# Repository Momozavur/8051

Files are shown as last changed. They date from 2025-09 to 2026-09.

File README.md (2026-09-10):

# 8051

KiCad design files for 8051.

## Project files

- [8051 Breakout Board/8051_breakout.kicad_pro](8051%20Breakout%20Board/8051_breakout.kicad_pro)
- [8051 Development Board v2/8051.kicad_pro](8051%20Development%20Board%20v2/8051.kicad_pro)
- [8051 Development Board/8051.kicad_pro](8051%20Development%20Board/8051.kicad_pro)
- [8051 ultra/Ultra_DB_X51_v1.kicad_pro](8051%20ultra/Ultra_DB_X51_v1.kicad_pro)
- [8051 ultra/Ultra_DB_X51_v1.pro](8051%20ultra/Ultra_DB_X51_v1.pro)
- [8051 ultra/file549BD866.kicad_pro](8051%20ultra/file549BD866.kicad_pro)
- [8051 ultra/file549BD866.pro](8051%20ultra/file549BD866.pro)
- [8051 ultra/file549BDEFB.pro](8051%20ultra/file549BDEFB.pro)
- [8051 ultra/file549BE66B.pro](8051%20ultra/file549BE66B.pro)

Open the appropriate `.kicad_pro` file in KiCad; `.pro` entries are legacy projects. Keep schematics, boards, local libraries, library tables, and supporting files together. Hierarchical schematic sheets are part of their parent design.

## Git workflow

Automatic backups, recovery files, editor state, and filesystem metadata are ignored. Existing fabrication outputs and local component libraries are retained. For existing repositories, ignore rules do not automatically untrack previously committed files.

Review and save a meaningful design revision with:

```sh
git status --short
git diff
git add -- <changed-files>
git commit -m "Describe the design change"
```

## Documentation images

Add a clear 3D board view at `docs/images/board-3d.png` and, optionally, a PCB layout view at `docs/images/pcb-layout.png`. A schematic PDF is useful for reading circuit details. Once present, embed an image in this README with `![Board 3D view](docs/images/board-3d.png)`. For folders with several designs, use a separate named image for each.

## Design notes to complete

Describe purpose, power and connectors, revision status, assembly requirements, and what has been physically tested. The repository setup does not establish electrical correctness or manufacturing readiness.

## Repository portability notes

- Computer-specific library path: `8051 ultra/fp-lib-table` → `H:\\PCB_Designes\\LPC1768 Stick1\\lib_new\\logo.pretty`.
- Computer-specific library path: `8051 ultra/fp-lib-table` → `H:\\PCB_Designes\\LPC1768 Stick1\\lib_new\\New_Logo.pretty`.

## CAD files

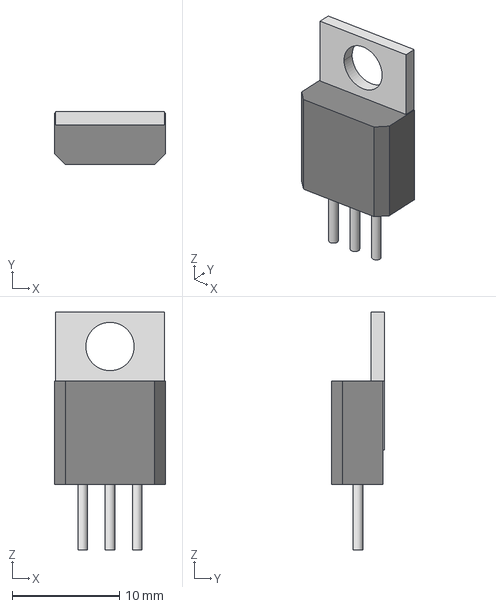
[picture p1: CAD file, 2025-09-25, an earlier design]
8051 Development Board v2/imports/2SA2222SG/TO-220F-3SG_15P87X10P16_ONS.step
10.4 x 4.90 x 22.2 mm

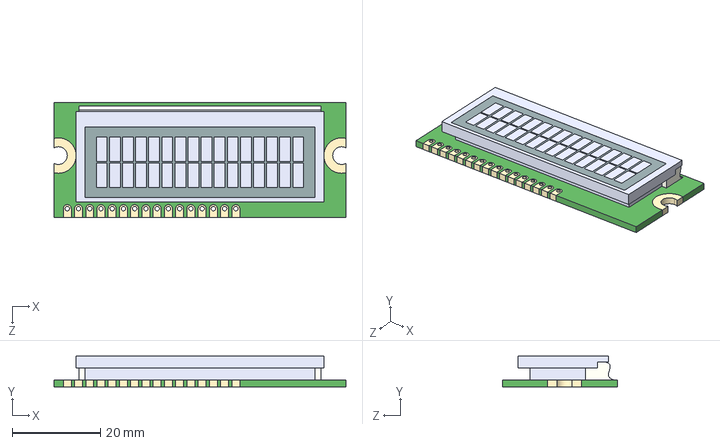
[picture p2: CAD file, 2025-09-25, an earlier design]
8051 Development Board v2/imports/LCM_S01602DTR_M/LCM-S01602DTR_M.STEP
66.0 x 7.00 x 26.0 mm

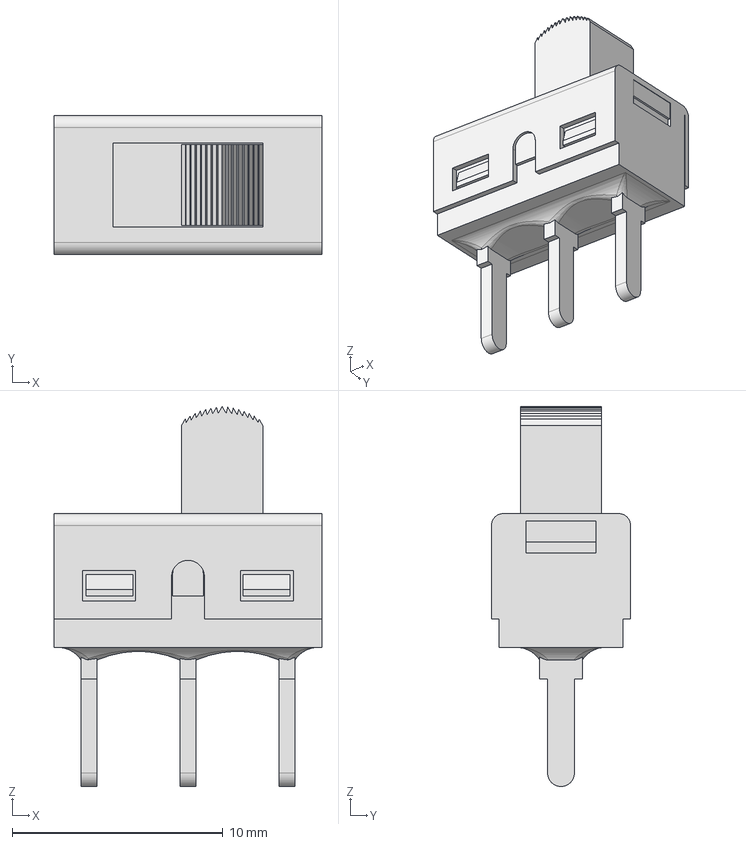
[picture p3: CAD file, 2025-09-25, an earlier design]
8051 Development Board v2/imports/LIB_500SSP1S1M2QEA/500SSP1S1M2QEA/3D/500SSP1S1M2QEA.stp
12.7 x 6.60 x 18.0 mm

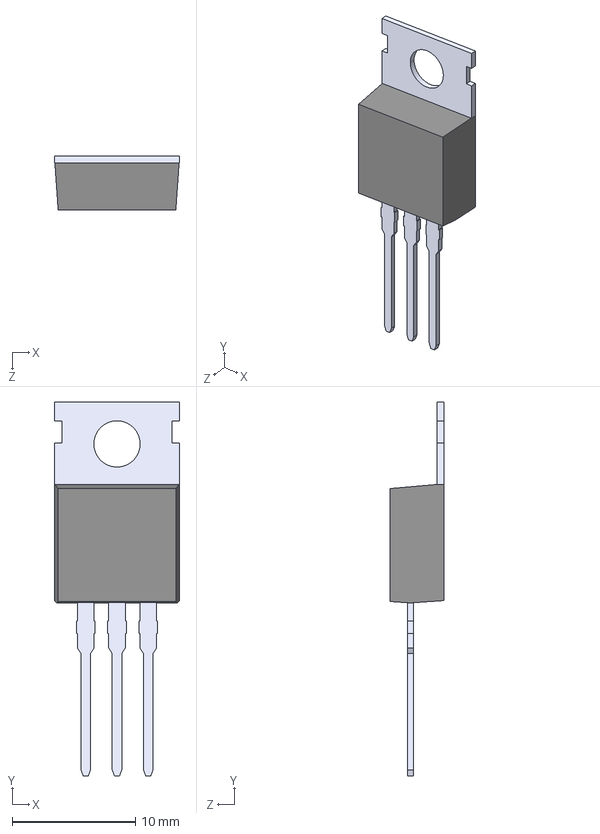
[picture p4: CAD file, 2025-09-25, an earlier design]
8051 Development Board v2/imports/LM7805CT/LM7805CT_NOPB.step
10.2 x 30.3 x 4.35 mm

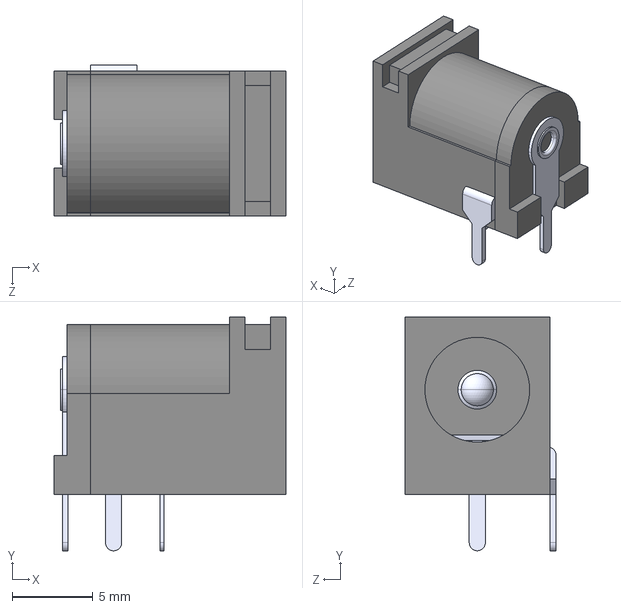
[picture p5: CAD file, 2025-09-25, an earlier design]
8051 Development Board v2/imports/PJ_102A-2/PJ-102A.step
14.4 x 14.5 x 9.40 mm

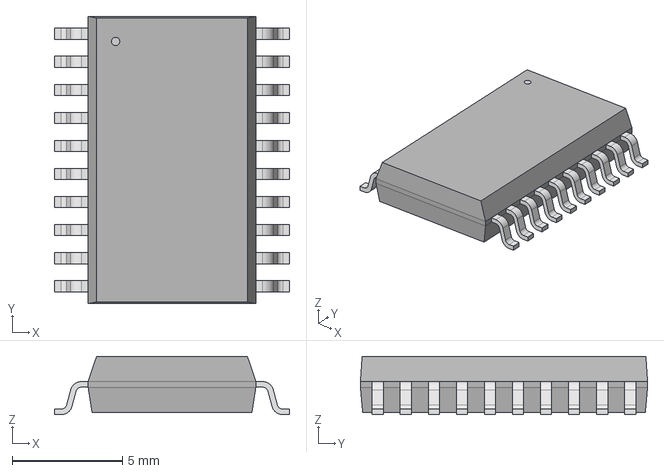
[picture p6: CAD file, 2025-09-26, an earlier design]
8051 Development Board v2/imports/SOIC20_12P7X5P4_ONS.step
10.6 x 13.0 x 2.64 mm

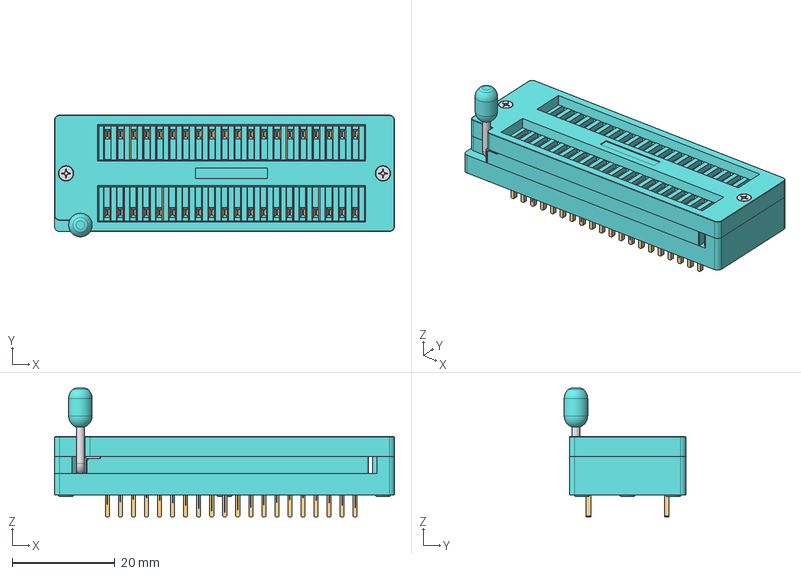
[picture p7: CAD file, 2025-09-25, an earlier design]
8051 Development Board v2/imports/ZIF_40_uni.stp
66.2 x 23.7 x 25.1 mm
ZIF_40uni_bottom
ZIF_40uni_middle_body
ZIF_wide_middle_shield
ZIF_40uni_top
ZIF_handle_wide
ZIF_socket_handle_head
ZIF_socket_pin_uni x 40
M1.6-L8 x 2

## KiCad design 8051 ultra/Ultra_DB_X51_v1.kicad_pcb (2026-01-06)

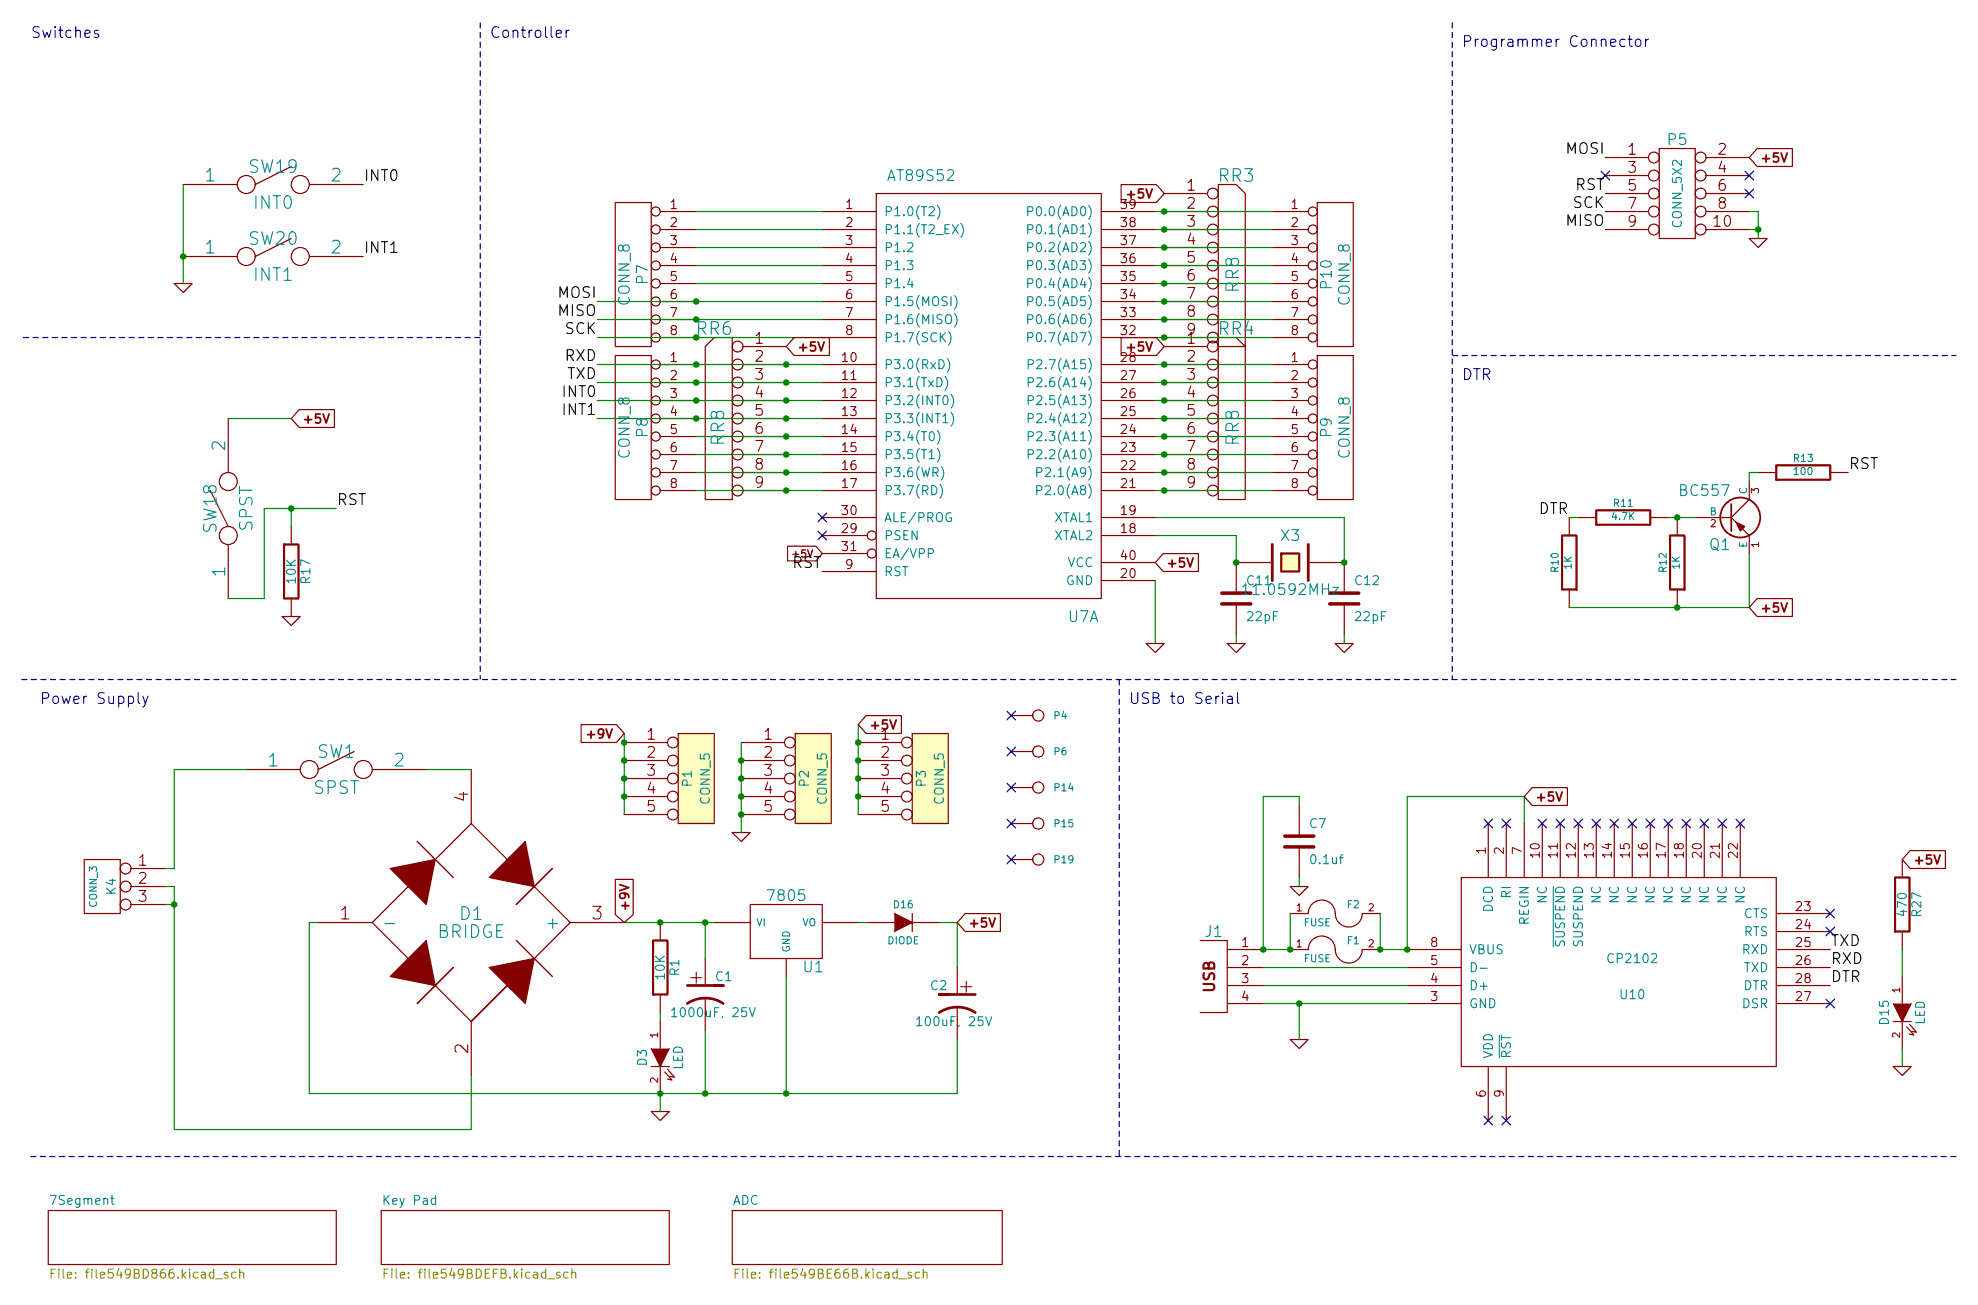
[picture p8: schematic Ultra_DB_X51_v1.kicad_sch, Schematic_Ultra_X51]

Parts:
C1: 1000uF, 25V
C2: 100uF, 25V
C7: 0.1uf
C11, C12: 22pF
D1: BRIDGE
D3, D15: LED
D16: DIODE
F1, F2: FUSE
J1: USB_2
K4: CONN_3
P1, P2, P3: CONN_5
P4, P6, P14, P15, P19: CONN_1
P5: CONN_5X2
P7, P8, P9, P10: CONN_8
Q1: BC557
R1, R17: 10K
R10, R12: 1K
R11: 4.7K
R13: 100
R27: 470
RR3, RR4, RR6: RR8
SW1, SW18: SPST
SW19: INT0
SW20: INT1
U1: 7805
U7: AT89S52
U10: CP2102; MODULE
X3: 11.0592MHz

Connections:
+5V: C2.1, D16.2 (K), F1.2, F2.2, P3.1, P3.2, P3.3, P3.4, P3.5, P5.2, Q1.1 (E), R10.1, R12.1, R27.2, RR3.1 (COM), RR4.1 (COM), RR6.1 (COM), SW18.2, U7.31 (EA/VPP), U7.40 (VCC), U10.7 (REGIN), U10.8 (VBUS); also elsewhere on the board
+9V: C1.1, D1.3 (+), P1.1, P1.2, P1.3, P1.4, P1.5, R1.2, U1.VI; also elsewhere on the board
/DTR: R10.2, R11.1, U10.28 (DTR)
/INT0: P8.3, RR6.4, SW19.2, U7.12 (P3.2(INT0))
/INT1: P8.4, RR6.5, SW20.2, U7.13 (P3.3(INT1))
/MISO: P5.9, P7.7, U7.7 (P1.6(MISO))
/MOSI: P5.1, P7.6, U7.6 (P1.5(MOSI))
/RST: P5.5, R13.2, R17.1, SW18.1, U7.9 (RST)
/RXD: P8.1, RR6.2, U7.10 (P3.0(RxD)), U10.26 (TXD)
/SCK: P5.7, P7.8, U7.8 (P1.7(SCK))
/TXD: P8.2, RR6.3, U7.11 (P3.1(TxD)), U10.25 (RXD)
GND: C1.2, C2.2, C7.2, C11.2, C12.2, D1.1 (-), D3.2 (K), D15.2 (K), J1.4, P2.1, P2.2, P2.3, P2.4, P2.5, P5.8, P5.10, R17.2, SW19.1, SW20.1, U1.GND, U7.20 (GND), U10.3 (GND); also elsewhere on the board
unnamed: J1.2, U10.5 (D-)
unnamed: Q1.2 (B), R11.2, R12.2
unnamed: J1.3, U10.4 (D+)
unnamed: Q1.3 (C), R13.1
unnamed: C7.1, F1.1, F2.1, J1.1
unnamed: D1.2, K4.2 (PM), K4.3
unnamed: P7.5, U7.5 (P1.4)
unnamed: P7.4, U7.4 (P1.3)
unnamed: P7.3, U7.3 (P1.2)
unnamed: P7.2, U7.2 (P1.1(T2_EX))
unnamed: P7.1, U7.1 (P1.0(T2))
unnamed: D16.1 (A), U1.VO
unnamed: C12.1, U7.19 (XTAL1), X3.2
unnamed: C11.1, U7.18 (XTAL2), X3.1
unnamed: D3.1 (A), R1.1
unnamed: D15.1 (A), R27.1
unnamed: K4.1, SW1.1
unnamed: D1.4, SW1.2
unnamed: P8.5, RR6.6, U7.14 (P3.4(T0))
unnamed: P8.8, RR6.9, U7.17 (P3.7(RD))
unnamed: P8.7, RR6.8, U7.16 (P3.6(WR))
unnamed: P8.6, RR6.7, U7.15 (P3.5(T1))
unnamed: P9.8, RR4.9, U7.21 (P2.0(A8))
unnamed: P9.7, RR4.8, U7.22 (P2.1(A9))
unnamed: P9.6, RR4.7, U7.23 (P2.2(A10))
unnamed: P9.5, RR4.6, U7.24 (P2.3(A11))
unnamed: P9.4, RR4.5, U7.25 (P2.4(A12))
unnamed: P9.3, RR4.4, U7.26 (P2.5(A13))
unnamed: P9.2, RR4.3, U7.27 (P2.6(A14))
unnamed: P9.1, RR4.2, U7.28 (P2.7(A15))
unnamed: P10.2, RR3.3, U7.38 (P0.1(AD1))
unnamed: P10.8, RR3.9, U7.32 (P0.7(AD7))
unnamed: P10.7, RR3.8, U7.33 (P0.6(AD6))
unnamed: P10.6, RR3.7, U7.34 (P0.5(AD5))
unnamed: P10.5, RR3.6, U7.35 (P0.4(AD4))
unnamed: P10.4, RR3.5, U7.36 (P0.3(AD3))
unnamed: P10.3, RR3.4, U7.37 (P0.2(AD2))
unnamed: P10.1, RR3.2, U7.39 (P0.0(AD0))

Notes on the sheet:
DTR
Switches
Power Supply
Programmer Connector
Controller
USB to Serial

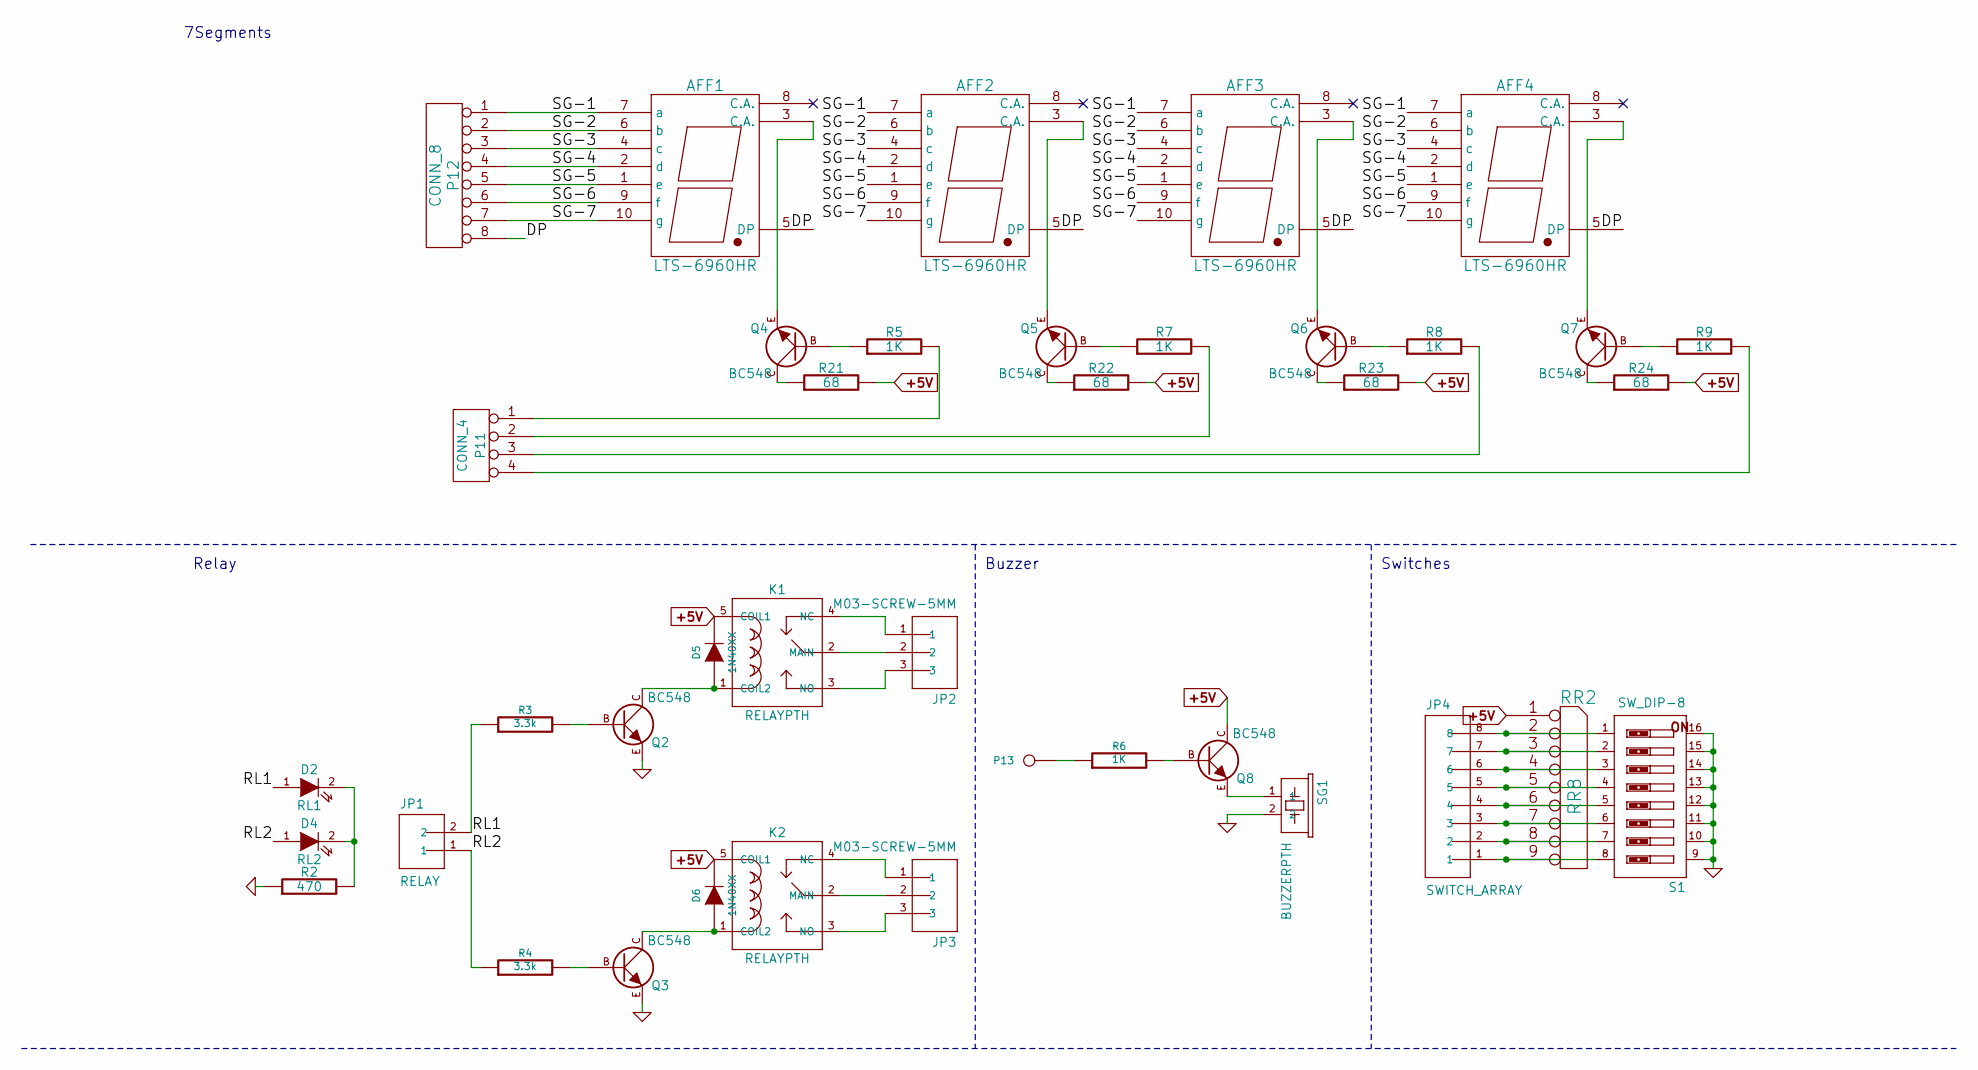
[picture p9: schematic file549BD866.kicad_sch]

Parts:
AFF1, AFF2, AFF3, AFF4: LTS-6960HR
D2: RL1
D4: RL2
D5, D6: 1N40XX
JP1: RELAY; SparkFun-JST-2-PTH-NS
JP2, JP3: M03-SCREW-5MM; SparkFun-SCREWTERMINAL-5MM-3
JP4: SWITCH_ARRAY; SparkFun-1X08_LOCK
K1, K2: RELAYPTH
P11: CONN_4
P12: CONN_8
P13: CONN_1
Q2, Q3, Q4, Q5, Q6, Q7, Q8: BC548; TO92-EBC
R2: 470
R3, R4: 3.3k
R5, R7, R8, R9: 1K
R6: 1K
R21, R22, R23, R24: 68
RR2: RR8
S1: SW_DIP-8; SparkFun-DIPSWITCH-08
SG1: BUZZERPTH; SparkFun-BUZZER-12MM

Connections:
+5V: D5.2 (K), D6.2 (K), K1.5 (COIL1), K2.5 (COIL1), Q8.C, R21.2, R22.2, R23.2, R24.2, RR2.1 (COM); also elsewhere on the board
/7Segment/DP: AFF1.5 (DP), AFF2.5 (DP), AFF3.5 (DP), AFF4.5 (DP), P12.8
/7Segment/RL1: D2.1 (A), JP1.2, R3.1
/7Segment/RL2: D4.1 (A), JP1.1, R4.1
/7Segment/SG-1: AFF1.7 (a), AFF2.7 (a), AFF3.7 (a), AFF4.7 (a), P12.1
/7Segment/SG-2: AFF1.6 (b), AFF2.6 (b), AFF3.6 (b), AFF4.6 (b), P12.2
/7Segment/SG-3: AFF1.4 (c), AFF2.4 (c), AFF3.4 (c), AFF4.4 (c), P12.3
/7Segment/SG-4: AFF1.2 (d), AFF2.2 (d), AFF3.2 (d), AFF4.2 (d), P12.4
/7Segment/SG-5: AFF1.1 (e), AFF2.1 (e), AFF3.1 (e), AFF4.1 (e), P12.5
/7Segment/SG-6: AFF1.9 (f), AFF2.9 (f), AFF3.9 (f), AFF4.9 (f), P12.6
/7Segment/SG-7: AFF1.10 (g), AFF2.10 (g), AFF3.10 (g), AFF4.10 (g), P12.7
GND: Q2.E, Q3.E, R2.1, S1.9, S1.10, S1.11, S1.12, S1.13, S1.14, S1.15, S1.16, SG1.2; also elsewhere on the board
unnamed: Q2.B, R3.2
unnamed: Q3.B, R4.2
unnamed: D6.1 (A), K2.1 (COIL2), Q3.C
unnamed: P11.1, R5.2
unnamed: D5.1 (A), K1.1 (COIL2), Q2.C
unnamed: P11.4, R9.2
unnamed: P11.3, R8.2
unnamed: P11.2, R7.2
unnamed: Q8.E, SG1.1
unnamed: Q8.B, R6.2
unnamed: P13.1, R6.1
unnamed: AFF4.3 (C.A.), Q7.E
unnamed: Q7.C, R24.1
unnamed: Q6.C, R23.1
unnamed: Q5.C, R22.1
unnamed: Q4.C, R21.1
unnamed: AFF2.3 (C.A.), Q5.E
unnamed: JP2.3, K1.3 (NO)
unnamed: JP2.2, K1.2 (MAIN)
unnamed: JP2.1, K1.4 (NC)
unnamed: JP4.8, RR2.2, S1.1
unnamed: JP3.1, K2.4 (NC)
unnamed: JP3.2, K2.2 (MAIN)
unnamed: D2.2 (K), D4.2 (K), R2.2
unnamed: JP4.1, RR2.9, S1.8
unnamed: JP4.2, RR2.8, S1.7
unnamed: JP4.3, RR2.7, S1.6
unnamed: JP4.4, RR2.6, S1.5
unnamed: JP4.5, RR2.5, S1.4
unnamed: JP4.6, RR2.4, S1.3
unnamed: JP4.7, RR2.3, S1.2
unnamed: JP3.3, K2.3 (NO)
unnamed: Q6.B, R8.1
unnamed: Q7.B, R9.1
unnamed: Q4.B, R5.1
unnamed: Q5.B, R7.1
unnamed: AFF1.3 (C.A.), Q4.E
unnamed: AFF3.3 (C.A.), Q6.E

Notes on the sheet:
7Segments
Buzzer
Switches
Relay

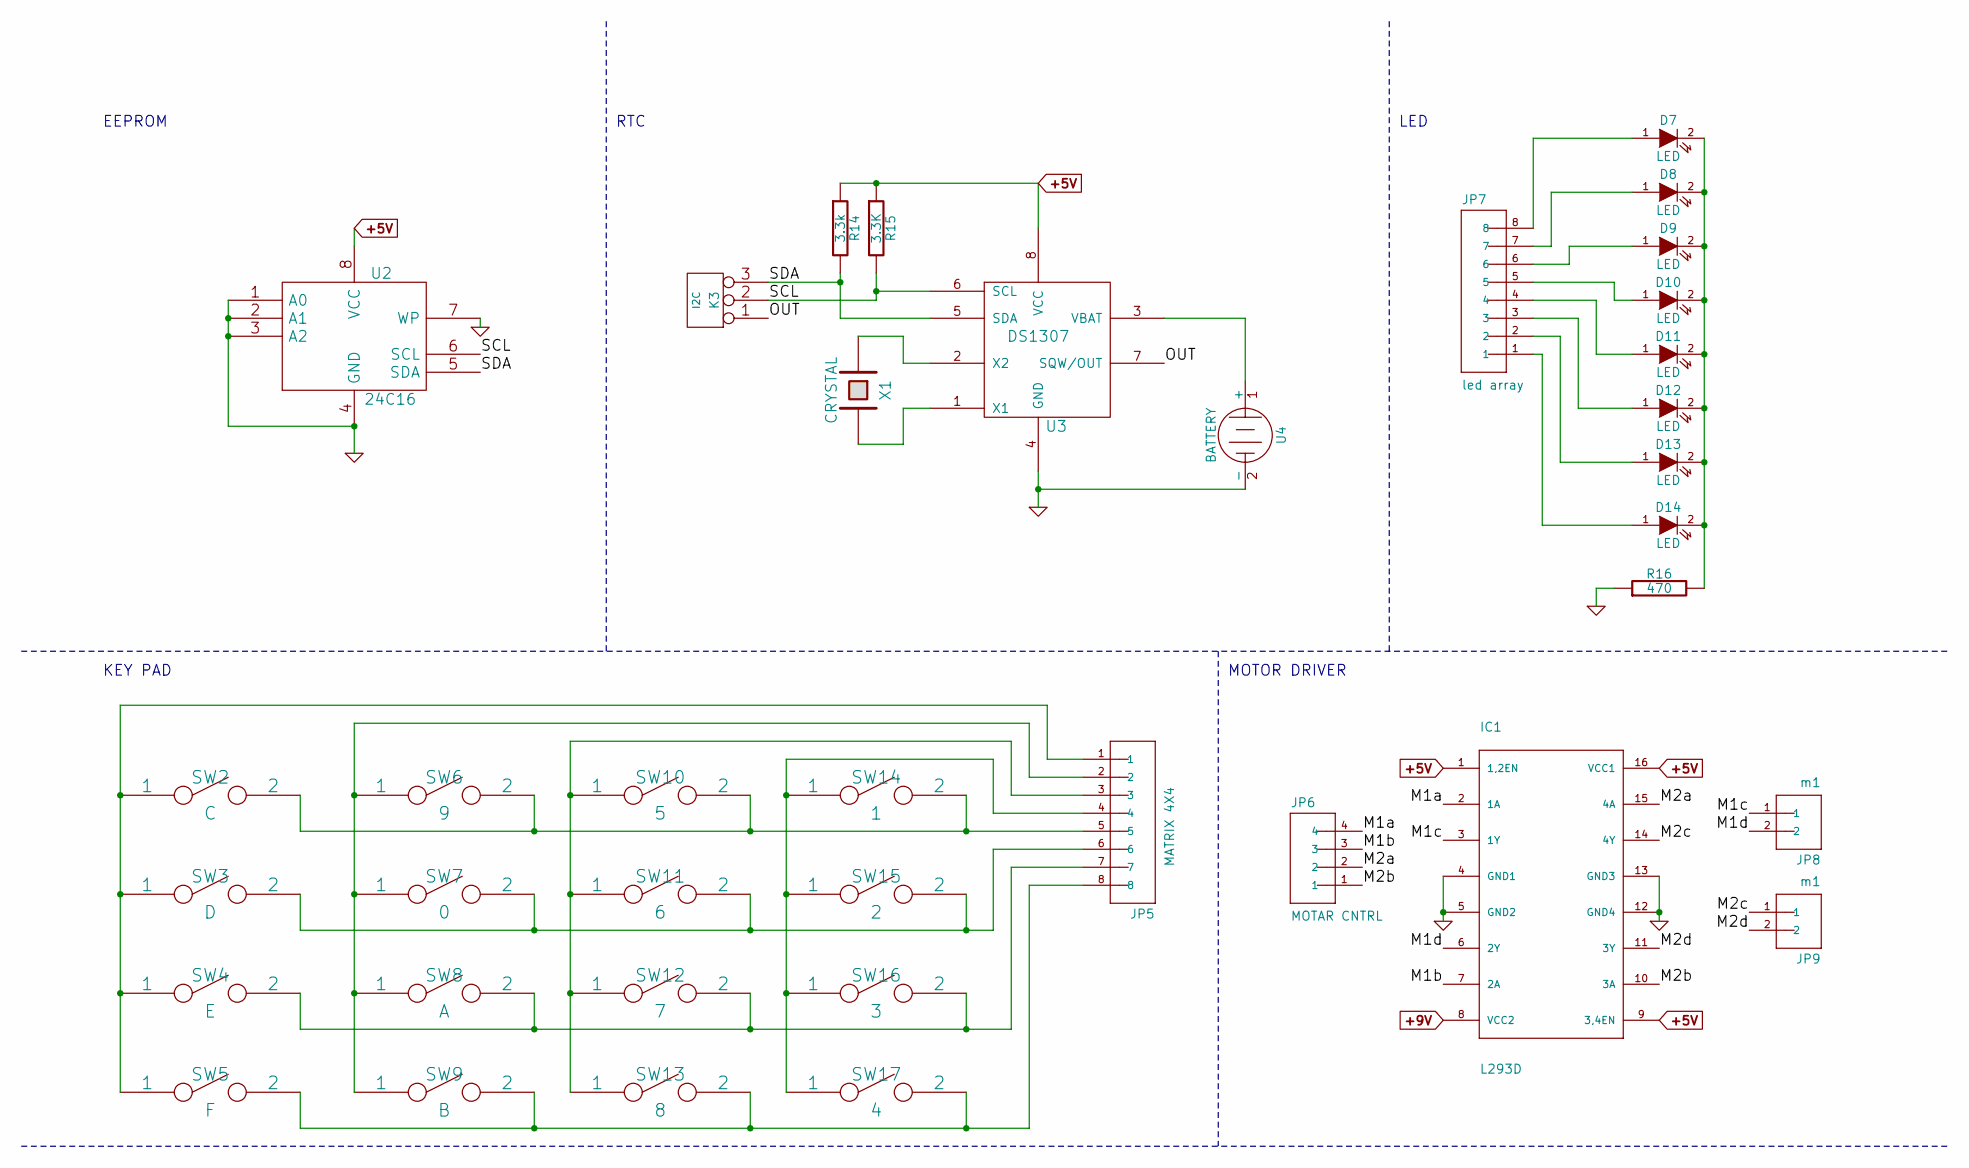
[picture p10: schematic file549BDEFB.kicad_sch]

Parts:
D7, D8, D9, D10, D11, D12, D13, D14: LED
IC1: L293D; sgs-thom-DIL16
JP5: MATRIX 4X4; SparkFun-1X08_LOCK
JP6: MOTAR CNTRL; SparkFun-JST-4-PTH
JP7: led array; SparkFun-1X08_LOCK
JP8, JP9: m1; SparkFun-JST-2-PTH-NS
K3: I2C
R14: 3.3k
R15: 3.3K
R16: 470
SW2: C
SW3: D
SW4: E
SW5: F
SW6: 9
SW7: 0
SW8: A
SW9: B
SW10: 5
SW11: 6
SW12: 7
SW13: 8
SW14: 1
SW15: 2
SW16: 3
SW17: 4
U2: 24C16
U3: DS1307
U4: BATTERY
X1: CRYSTAL

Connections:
+5V: IC1.1 (1,2EN), IC1.9 (3,4EN), IC1.16 (VCC1), R14.1, R15.1, U2.8 (VCC), U3.8 (VCC); also elsewhere on the board
+9V: IC1.8 (VCC2); also elsewhere on the board
/Key Pad/M1a: IC1.2 (1A), JP6.4
/Key Pad/M1b: IC1.7 (2A), JP6.3
/Key Pad/M1c: IC1.3 (1Y), JP8.1
/Key Pad/M1d: IC1.6 (2Y), JP8.2
/Key Pad/M2a: IC1.15 (4A), JP6.2
/Key Pad/M2b: IC1.10 (3A), JP6.1
/Key Pad/M2c: IC1.14 (4Y), JP9.1
/Key Pad/M2d: IC1.11 (3Y), JP9.2
/Key Pad/OUT: K3.1, U3.7 (SQW/OUT)
/Key Pad/SCL: K3.2 (PM), R15.2, U2.6 (SCL), U3.6 (SCL)
/Key Pad/SDA: K3.3, R14.2, U2.5 (SDA), U3.5 (SDA)
GND: IC1.4 (GND1), IC1.5 (GND2), IC1.12 (GND4), IC1.13 (GND3), R16.1, U2.1 (A0), U2.2 (A1), U2.3 (A2), U2.4 (GND), U2.7 (WP), U3.4 (GND), U4.2 (-); also elsewhere on the board
unnamed: D8.1 (A), JP7.7
unnamed: D9.1 (A), JP7.6
unnamed: D10.1 (A), JP7.5
unnamed: D11.1 (A), JP7.4
unnamed: D12.1 (A), JP7.3
unnamed: D13.1 (A), JP7.2
unnamed: D7.1 (A), JP7.8
unnamed: U3.2 (X2), X1.1
unnamed: U3.1 (X1), X1.2
unnamed: U3.3 (VBAT), U4.1 (+)
unnamed: D14.1 (A), JP7.1
unnamed: JP5.7, SW4.2, SW8.2, SW12.2, SW16.2
unnamed: JP5.8, SW5.2, SW9.2, SW13.2, SW17.2
unnamed: JP5.5, SW2.2, SW6.2, SW10.2, SW14.2
unnamed: JP5.6, SW3.2, SW7.2, SW11.2, SW15.2
unnamed: JP5.3, SW10.1, SW11.1, SW12.1, SW13.1
unnamed: JP5.2, SW6.1, SW7.1, SW8.1, SW9.1
unnamed: JP5.4, SW14.1, SW15.1, SW16.1, SW17.1
unnamed: JP5.1, SW2.1, SW3.1, SW4.1, SW5.1
unnamed: D7.2 (K), D8.2 (K), D9.2 (K), D10.2 (K), D11.2 (K), D12.2 (K), D13.2 (K), D14.2 (K), R16.2

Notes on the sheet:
EEPROM
KEY PAD
LED
RTC
MOTOR DRIVER

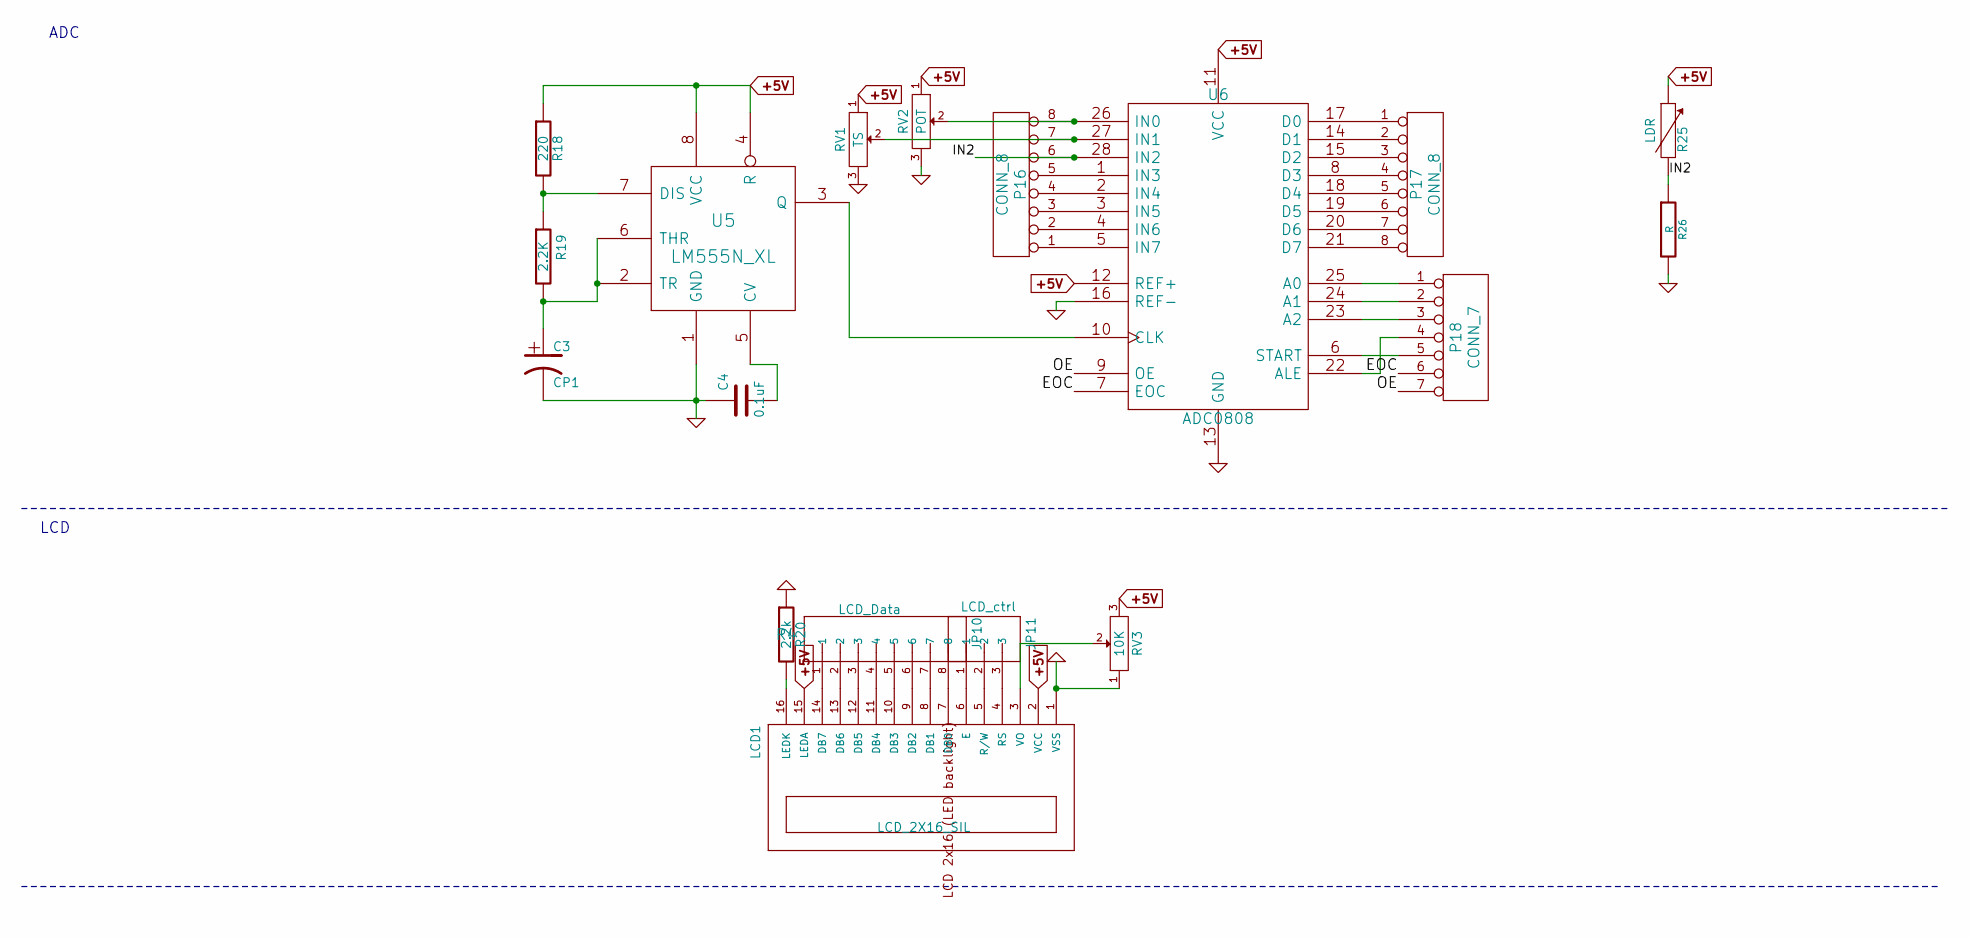
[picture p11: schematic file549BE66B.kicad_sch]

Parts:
C3: CP1
C4: 0.1uF
JP10: LCD_Data; SparkFun-1X08
JP11: LCD_ctrl; SparkFun-SCREWTERMINAL-5MM-3
LCD1: LCD_2X16_SIL; lcd_2x16_led_backlight-HY-1602F
P16, P17: CONN_8
P18: CONN_7
R18: 220
R19: 2.2K
R20: 2.2k; R4
R25: LDR
R26: R
RV1: TS
RV2: POT
RV3: 10K
U5: LM555N_XL
U6: ADC0808

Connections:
+5V: LCD1.2 (VCC), LCD1.15 (LEDA), R18.1, R25.1, RV1.1, RV2.1, RV3.3, U5.4 (R), U5.8 (VCC), U6.11 (VCC), U6.12 (REF+); also elsewhere on the board
/ADC/EOC: P18.6, U6.7 (EOC)
/ADC/IN2: P16.6, R25.2, R26.1, U6.28 (IN2)
/ADC/OE: P18.7, U6.9 (OE)
GND: C3.2, C4.1, LCD1.1 (VSS), R20.1, R26.2, RV1.3, RV2.3, RV3.1, U5.1 (GND), U6.13 (GND), U6.16 (REF-); also elsewhere on the board
unnamed: LCD1.16 (LEDK), R20.2
unnamed: JP11.1, LCD1.6 (E)
unnamed: JP10.1, LCD1.14 (DB7)
unnamed: JP11.2, LCD1.5 (R/W)
unnamed: JP11.3, LCD1.4 (RS)
unnamed: P18.5, U6.6 (START)
unnamed: P18.4, U6.22 (ALE)
unnamed: JP10.2, LCD1.13 (DB6)
unnamed: JP10.3, LCD1.12 (DB5)
unnamed: JP10.4, LCD1.11 (DB4)
unnamed: JP10.5, LCD1.10 (DB3)
unnamed: JP10.6, LCD1.9 (DB2)
unnamed: JP10.7, LCD1.8 (DB1)
unnamed: JP10.8, LCD1.7 (DB0)
unnamed: C4.2, U5.5 (CV)
unnamed: R18.2, R19.1, U5.7 (DIS)
unnamed: P18.3, U6.23 (A2)
unnamed: P16.8, RV2.2, U6.26 (IN0)
unnamed: P16.7, RV1.2, U6.27 (IN1)
unnamed: U5.3 (Q), U6.10 (CLK)
unnamed: P18.1, U6.25 (A0)
unnamed: P18.2, U6.24 (A1)
unnamed: LCD1.3 (VO), RV3.2
unnamed: P17.2, U6.14 (D1)
unnamed: P17.3, U6.15 (D2)
unnamed: P17.1, U6.17 (D0)
unnamed: P17.5, U6.18 (D4)
unnamed: P17.6, U6.19 (D5)
unnamed: C3.1, R19.2, U5.2 (TR), U5.6 (THR)
unnamed: P16.2, U6.4 (IN6)
unnamed: P16.5, U6.1 (IN3)
unnamed: P16.4, U6.2 (IN4)
unnamed: P16.3, U6.3 (IN5)
unnamed: P16.1, U6.5 (IN7)
unnamed: P17.4, U6.8 (D3)
unnamed: P17.7, U6.20 (D6)
unnamed: P17.8, U6.21 (D7)

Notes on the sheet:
LCD
ADC

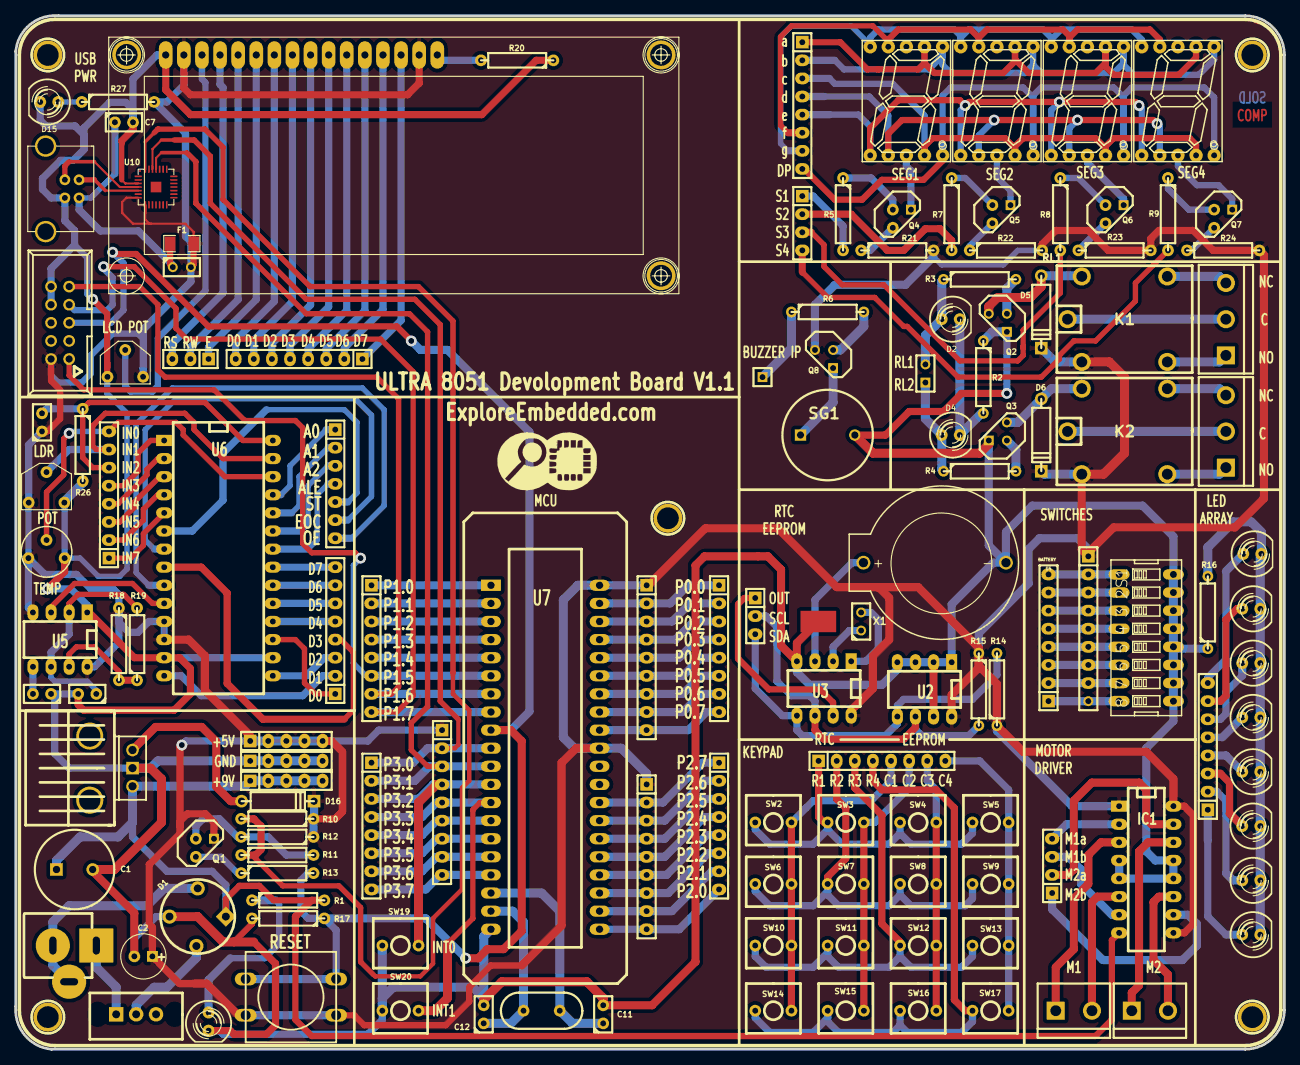
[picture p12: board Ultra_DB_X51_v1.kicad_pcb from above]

Board: 2 copper layers, 178.0 x 145.0 mm, 142 parts (1 on the bottom side), 169 nets.

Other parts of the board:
LOGO: LOGO (1)
VAL: REF; Logo_16

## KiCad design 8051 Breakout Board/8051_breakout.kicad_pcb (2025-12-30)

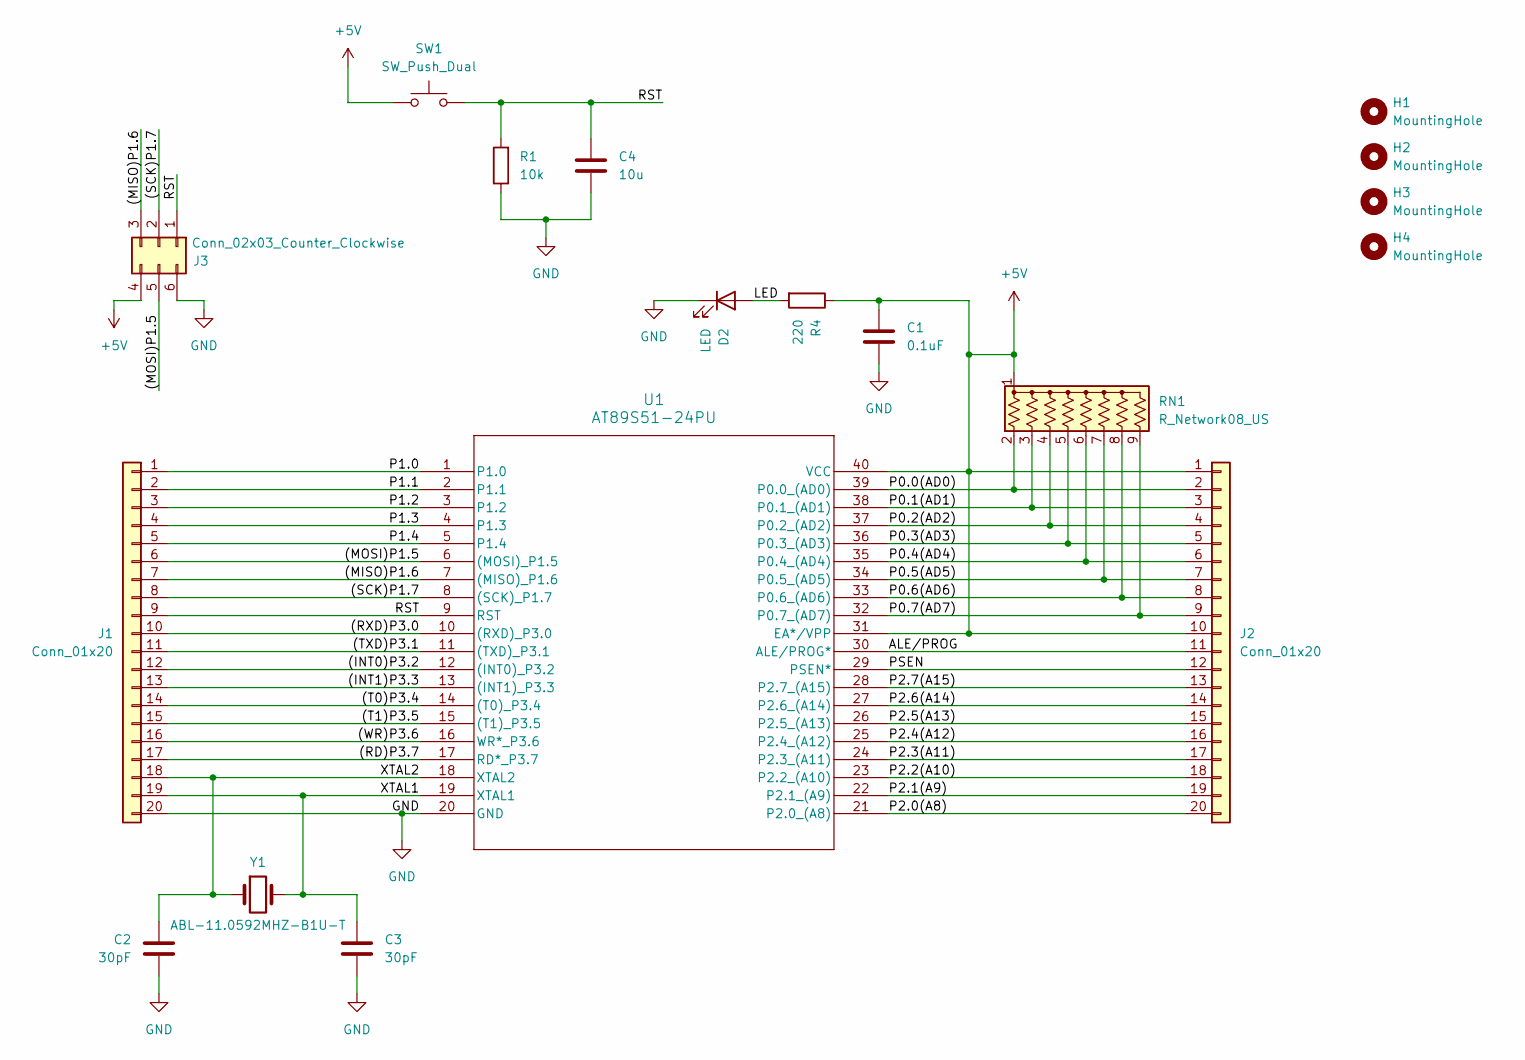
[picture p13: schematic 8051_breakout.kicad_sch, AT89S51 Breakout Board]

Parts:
C1: 0.1uF; C_0805_2012Metric_Pad1.18x1.45mm_HandSolder
C2, C3: 30pF; C_0805_2012Metric_Pad1.18x1.45mm_HandSolder
C4: 10u; C_0805_2012Metric_Pad1.18x1.45mm_HandSolder
D2: LED; LED_0805_2012Metric_Pad1.15x1.40mm_HandSolder
H1, H2, H3, H4: MountingHole; MountingHole_2.2mm_M2_DIN965_Pad
J1, J2: Conn_01x20; PinHeader_1x20_P2.54mm_Vertical
J3: Conn_02x03_Counter_Clockwise; PinHeader_2x03_P2.54mm_Vertical
R1: 10k; R_0805_2012Metric_Pad1.20x1.40mm_HandSolder
R4: 220; R_0805_2012Metric_Pad1.20x1.40mm_HandSolder
RN1: R_Network08_US; R_Array_SIP9
SW1: SW_Push_Dual; SW_PUSH_6mm_H7.3mm
U1: AT89S51-24PU; 40P6_ATM
Y1: ABL-11.0592MHZ-B1U-T; Crystal_HC49-4H_Vertical

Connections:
+5V: C1.1, J2.1, J2.10, J3.4, R4.1, RN1.1 (common), SW1.1, U1.31 (EA*/VPP), U1.40 (VCC)
/(INT0)P3.2: J1.12, U1.12 ((INT0)_P3.2)
/(INT1)P3.3: J1.13, U1.13 ((INT1)_P3.3)
/(MISO)P1.6: J1.7, J3.3, U1.7 ((MISO)_P1.6)
/(MOSI)P1.5: J1.6, J3.5, U1.6 ((MOSI)_P1.5)
/(RD)P3.7: J1.17, U1.17 (RD*_P3.7)
/(RXD)P3.0: J1.10, U1.10 ((RXD)_P3.0)
/(SCK)P1.7: J1.8, J3.2, U1.8 ((SCK)_P1.7)
/(T0)P3.4: J1.14, U1.14 ((T0)_P3.4)
/(T1)P3.5: J1.15, U1.15 ((T1)_P3.5)
/(TXD)P3.1: J1.11, U1.11 ((TXD)_P3.1)
/(WR)P3.6: J1.16, U1.16 (WR*_P3.6)
/ALE/PROG: J2.11, U1.30 (ALE/PROG*)
/LED: D2.2 (A), R4.2
/P0.0(AD0): J2.2, RN1.2 (R1), U1.39 (P0.0_(AD0))
/P0.1(AD1): J2.3, RN1.3 (R2), U1.38 (P0.1_(AD1))
/P0.2(AD2): J2.4, RN1.4 (R3), U1.37 (P0.2_(AD2))
/P0.3(AD3): J2.5, RN1.5 (R4), U1.36 (P0.3_(AD3))
/P0.4(AD4): J2.6, RN1.6 (R5), U1.35 (P0.4_(AD4))
/P0.5(AD5): J2.7, RN1.7 (R6), U1.34 (P0.5_(AD5))
/P0.6(AD6): J2.8, RN1.8 (R7), U1.33 (P0.6_(AD6))
/P0.7(AD7): J2.9, RN1.9 (R8), U1.32 (P0.7_(AD7))
/P1.0: J1.1, U1.1 (P1.0)
/P1.1: J1.2, U1.2 (P1.1)
/P1.2: J1.3, U1.3 (P1.2)
/P1.3: J1.4, U1.4 (P1.3)
/P1.4: J1.5, U1.5 (P1.4)
/P2.0(A8): J2.20, U1.21 (P2.0_(A8))
/P2.1(A9): J2.19, U1.22 (P2.1_(A9))
/P2.2(A10): J2.18, U1.23 (P2.2_(A10))
/P2.3(A11): J2.17, U1.24 (P2.3_(A11))
/P2.4(A12): J2.16, U1.25 (P2.4_(A12))
/P2.5(A13): J2.15, U1.26 (P2.5_(A13))
/P2.6(A14): J2.14, U1.27 (P2.6_(A14))
/P2.7(A15): J2.13, U1.28 (P2.7_(A15))
/PSEN: J2.12, U1.29 (PSEN*)
/RST: C4.1, J1.9, J3.1, R1.2, SW1.2, U1.9 (RST)
/XTAL1: C3.1, J1.19, U1.19 (XTAL1), Y1.2
/XTAL2: C2.1, J1.18, U1.18 (XTAL2), Y1.1
GND: C1.2, C2.2, C3.2, C4.2, D2.1 (K), J1.20, J3.6, R1.1, U1.20 (GND)

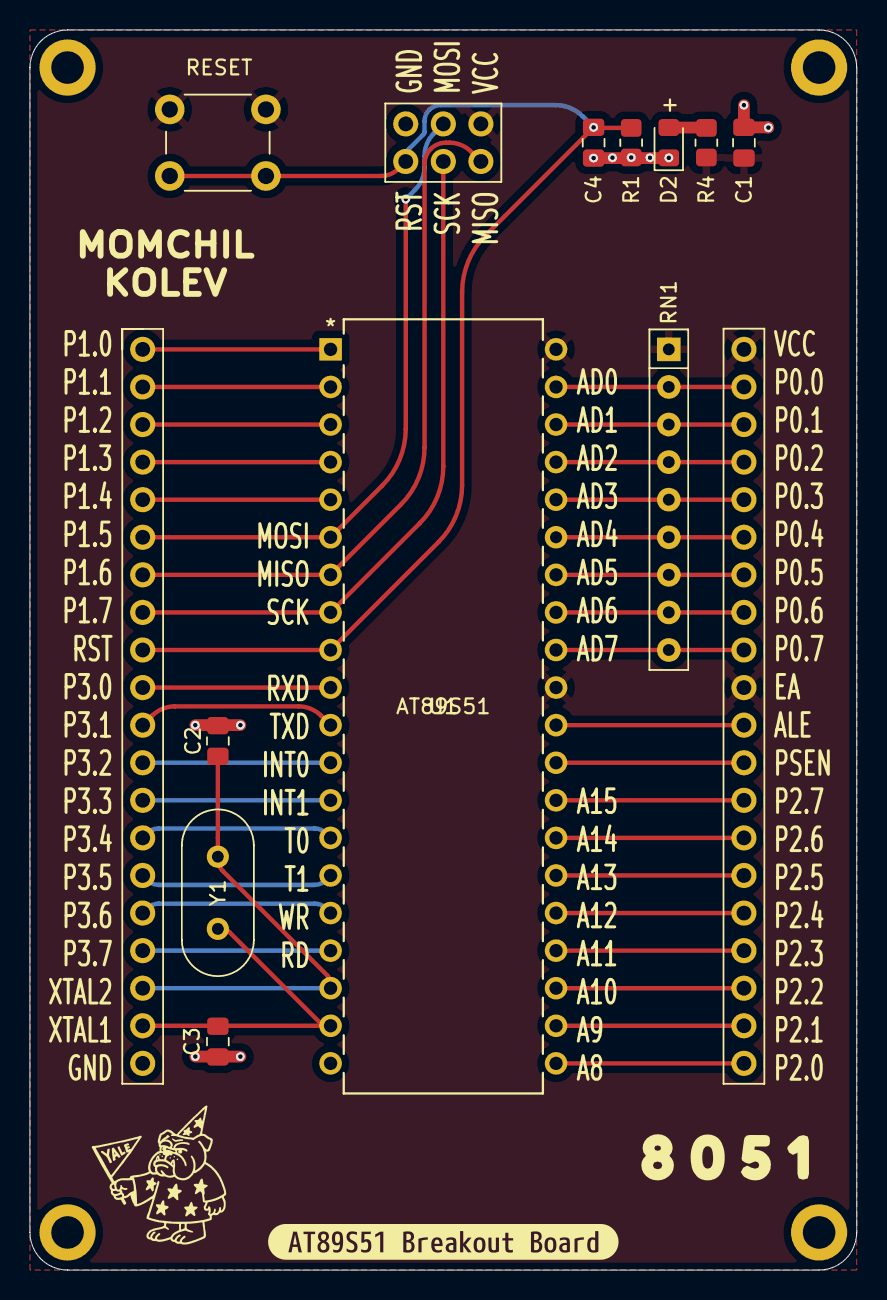
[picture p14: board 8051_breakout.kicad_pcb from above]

Board: 2 copper layers, 55.9 x 83.8 mm, 20 parts (0 on the bottom side), 40 nets.

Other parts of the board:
kibuzzard-68D5B3C4: G***; kibuzzard-68D5B3C4
kibuzzard-68D5FACE: G***; kibuzzard-68D5FACE

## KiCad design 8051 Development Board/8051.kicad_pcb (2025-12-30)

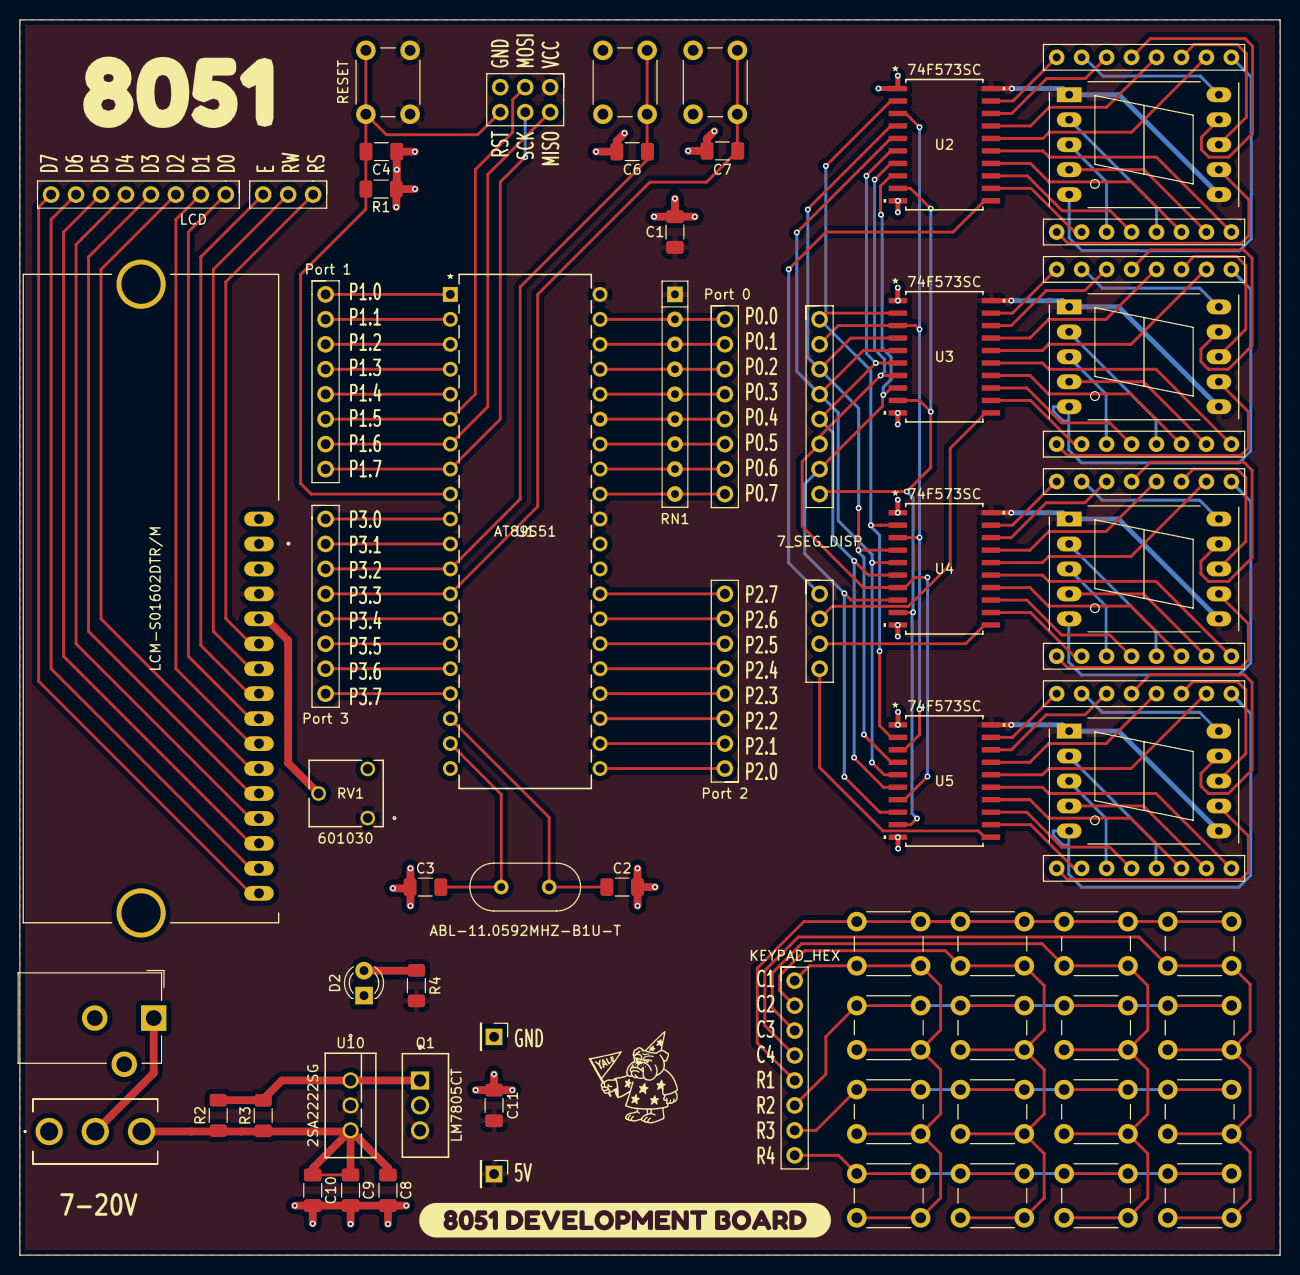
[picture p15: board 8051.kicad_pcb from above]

Board: 2 copper layers, 128.3 x 125.7 mm, 73 parts (0 on the bottom side), 137 nets.

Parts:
C1, C10, C11: 0.1uF; C_1206_3216Metric_Pad1.33x1.80mm_HandSolder
C2, C3: 30pF; C_1206_3216Metric_Pad1.33x1.80mm_HandSolder
C4: 10u; C_1206_3216Metric_Pad1.33x1.80mm_HandSolder
C6, C7, C9: 1uF; C_1206_3216Metric_Pad1.33x1.80mm_HandSolder
C8: 10uF; C_1206_3216Metric_Pad1.33x1.80mm_HandSolder
D2: LED; LED_D3.0mm
J1, J3, J4, J5, J8, J9, J12: Conn_01x08; PinHeader_1x08_P2.54mm_Vertical
J6: Conn_02x03_Counter_Clockwise; PinHeader_2x03_P2.54mm_Vertical
J10: LCM-S01602DTR_M; LCD_LCM-S01602DTR_M
J11: Conn_01x03; PinHeader_1x03_P2.54mm_Vertical
J13: Conn_01x04; PinHeader_1x04_P2.54mm_Vertical
J14: PJ-102A; BarrelJack_CUI_PJ-102AH_Horizontal
J15, J16: Conn_01x01; PinHeader_1x01_P2.54mm_Vertical
Q1: LM7805CT_NOPB; TO254P1054X470X2600-3
R1: 10k; R_1206_3216Metric_Pad1.30x1.75mm_HandSolder
R2, R3: 2; R_1206_3216Metric_Pad1.30x1.75mm_HandSolder
R4: 150; R_1206_3216Metric_Pad1.30x1.75mm_HandSolder
RN1: R_Network08_US; R_Array_SIP9
RN2, RN3, RN4, RN5, RN6, RN7, RN8, RN9: R_Pack04_SIP; R_Array_SIP8
RV1: 601030; 601030_AVX
SW1, SW2, SW3, SW4, SW5, SW6, SW7, SW8, SW9, SW10, SW11, SW12, SW13, SW14, SW15, SW16, SW17, SW18, SW19: SW_Push_Dual; SW_PUSH_6mm_H7.3mm
SW20: SW_Nidec_CAS-120A1; 500SSP1S1M2QEA
U1: AT89S51-24PU; 40P6_ATM
U2, U3, U4, U5: 74F573SC; SOIC20_12P7X5P4_ONS
U6, U7, U8, U9: SC39-12EWA; 7SegmentLED_LTS6760_LTS6780
U10: 2SA2222SG; TO-220F-3SG_15P87X10P16_ONS
Y1: ABL-11.0592MHZ-B1U-T; Crystal_HC49-4H_Vertical
kibuzzard-68D8BB38: G***; kibuzzard-68D8BB38
kibuzzard-68D8BC51: G***; kibuzzard-68D8BC51

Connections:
+5V: C1.1, C11.1, J6.4, J10.2 (VDD), J16.1, Q1.3 (OUT), R4.1, RN1.1 (common), RV1.1, SW1.1, U1.31 (EA*/VPP), U1.40 (VCC), U2.20 (VCC), U3.20 (VCC), U4.20 (VCC), U5.20 (VCC), U6.1 (CC), U6.6 (CC), U7.1 (CC), U7.6 (CC), U8.1 (CC), U8.6 (CC), U9.1 (CC), U9.6 (CC), U10.2 (C)
/KEYPAD_HEX/C1: J8.1, SW4.4, SW5.4, SW6.4, SW7.4
/KEYPAD_HEX/C2: J8.2, SW8.4, SW9.4, SW10.4, SW11.4
/KEYPAD_HEX/C3: J8.3, SW12.4, SW13.4, SW14.4, SW15.4
/KEYPAD_HEX/C4: J8.4, SW16.4, SW17.4, SW18.4, SW19.4
/KEYPAD_HEX/R1: J8.5, SW4.1, SW8.1, SW12.1, SW16.1
/KEYPAD_HEX/R2: J8.6, SW5.1, SW9.1, SW13.1, SW17.1
/KEYPAD_HEX/R3: J8.7, SW6.1, SW10.1, SW14.1, SW18.1
/KEYPAD_HEX/R4: J8.8, SW7.1, SW11.1, SW15.1, SW19.1
/LCD/D0: J9.1, J10.7 (DB0)
/LCD/D1: J9.2, J10.8 (DB1)
/LCD/D2: J9.3, J10.9 (DB2)
/LCD/D3: J9.4, J10.10 (DB3)
/LCD/D4: J9.5, J10.11 (DB4)
/LCD/D5: J9.6, J10.12 (DB5)
/LCD/D6: J9.7, J10.13 (DB6)
/LCD/D7: J9.8, J10.14 (DB7)
/LCD/E: J10.6 (E), J11.3
/LCD/RS: J10.4 (RS), J11.1
/LCD/RW: J10.5 (R/~W), J11.2
/P0.0: J3.1, RN1.2 (R1), U1.39 (P0.0_(AD0))
/P0.1: J3.2, RN1.3 (R2), U1.38 (P0.1_(AD1))
/P0.2: J3.3, RN1.4 (R3), U1.37 (P0.2_(AD2))
/P0.3: J3.4, RN1.5 (R4), U1.36 (P0.3_(AD3))
/P0.4: J3.5, RN1.6 (R5), U1.35 (P0.4_(AD4))
/P0.5: J3.6, RN1.7 (R6), U1.34 (P0.5_(AD5))
/P0.6: J3.7, RN1.8 (R7), U1.33 (P0.6_(AD6))
/P0.7: J3.8, RN1.9 (R8), U1.32 (P0.7_(AD7))
/P1.0: J1.1, U1.1 (P1.0)
/P1.1: J1.2, U1.2 (P1.1)
/P1.2: J1.3, U1.3 (P1.2)
/P1.3: J1.4, U1.4 (P1.3)
/P1.4: J1.5, U1.5 (P1.4)
/P1.5: J1.6, J6.5, U1.6 ((MOSI)_P1.5)
/P1.6: J1.7, J6.3, U1.7 ((MISO)_P1.6)
/P1.7: J1.8, J6.2, U1.8 ((SCK)_P1.7)
/P2.0: J4.1, U1.21 (P2.0_(A8))
/P2.1: J4.2, U1.22 (P2.1_(A9))
/P2.2: J4.3, U1.23 (P2.2_(A10))
/P2.3: J4.4, U1.24 (P2.3_(A11))
/P2.4: J4.5, U1.25 (P2.4_(A12))
/P2.5: J4.6, U1.26 (P2.5_(A13))
/P2.6: J4.7, U1.27 (P2.6_(A14))
/P2.7: J4.8, U1.28 (P2.7_(A15))
/P3.0: J5.1, U1.10 ((RXD)_P3.0)
/P3.1: J5.2, U1.11 ((TXD)_P3.1)
/P3.2: C6.1, J5.3, SW2.3, U1.12 ((INT0)_P3.2)
/P3.3: C7.2, J5.4, SW3.3, U1.13 ((INT1)_P3.3)
/P3.4: J5.5, U1.14 ((T0)_P3.4)
/P3.5: J5.6, U1.15 ((T1)_P3.5)
/P3.6: J5.7, U1.16 (WR*_P3.6)
/P3.7: J5.8, U1.17 (RD*_P3.7)
/PWR/VIN: J14.1, SW20.2 (B)
/RST: C4.1, J6.1, R1.2, SW1.2, U1.9 (RST)
/XTAL1: C3.1, U1.19 (XTAL1), Y1.2
/XTAL2: C2.1, U1.18 (XTAL2), Y1.1
GND: C1.2, C2.2, C3.2, C4.2, C6.2, C7.1, C8.2, C9.2, C10.2, C11.2, D2.1 (K), J6.6, J10.1 (VSS), J14.2, J14.3, J15.1, Q1.2 (GND), R1.1, RV1.3, SW2.2, SW3.2, U1.20 (GND), U2.1 (*OE), U2.10 (GND), U3.1 (*OE), U3.10 (GND), U4.1 (*OE), U4.10 (GND), U5.1 (*OE), U5.10 (GND)
unnamed: D2.2 (A), R4.2
unnamed: J10.3 (VO), RV1.2
unnamed: J12.1, U2.2 (D0), U3.2 (D0), U4.2 (D0), U5.2 (D0)
unnamed: J12.2, U2.3 (D1), U3.3 (D1), U4.3 (D1), U5.3 (D1)
unnamed: J12.3, U2.4 (D2), U3.4 (D2), U4.4 (D2), U5.4 (D2)
unnamed: J12.4, U2.5 (D3), U3.5 (D3), U4.5 (D3), U5.5 (D3)
unnamed: J12.5, U2.6 (D4), U3.6 (D4), U4.6 (D4), U5.6 (D4)
unnamed: J12.6, U2.7 (D5), U3.7 (D5), U4.7 (D5), U5.7 (D5)
unnamed: J12.7, U2.8 (D6), U3.8 (D6), U4.8 (D6), U5.8 (D6)
unnamed: J12.8, U2.9 (D7), U3.9 (D7), U4.9 (D7), U5.9 (D7)
unnamed: J13.1, U2.11 (LE)
unnamed: J13.2, U3.11 (LE)
unnamed: J13.3, U4.11 (LE)
unnamed: J13.4, U5.11 (LE)
unnamed: Q1.1 (IN), R2.2, R3.2, U10.1 (B)
unnamed: RN2.1 (R1.1), U2.19 (O0)
unnamed: RN2.2 (R1.2), U6.10 (A)
unnamed: RN2.3 (R2.1), U2.18 (O1)
unnamed: RN2.4 (R2.2), U6.9 (B)
unnamed: RN2.5 (R3.1), U2.17 (O2)
unnamed: RN2.6 (R3.2), U6.8 (C)
unnamed: RN2.7 (R4.1), U2.16 (O3)
unnamed: RN2.8 (R4.2), U6.5 (D)
unnamed: RN3.1 (R1.1), U2.15 (O4)
unnamed: RN3.2 (R1.2), U6.4 (E)
unnamed: RN3.3 (R2.1), U2.14 (O5)
unnamed: RN3.4 (R2.2), U6.2 (F)
unnamed: RN3.5 (R3.1), U2.13 (O6)
unnamed: RN3.6 (R3.2), U6.3 (G)
unnamed: RN3.7 (R4.1), U2.12 (O7)
unnamed: RN3.8 (R4.2), U6.7 (DP)
unnamed: RN4.1 (R1.1), U3.19 (O0)
unnamed: RN4.2 (R1.2), U7.10 (A)
unnamed: RN4.3 (R2.1), U3.18 (O1)
unnamed: RN4.4 (R2.2), U7.9 (B)
unnamed: RN4.5 (R3.1), U3.17 (O2)
unnamed: RN4.6 (R3.2), U7.8 (C)
unnamed: RN4.7 (R4.1), U3.16 (O3)
unnamed: RN4.8 (R4.2), U7.5 (D)
unnamed: RN5.1 (R1.1), U3.15 (O4)
unnamed: RN5.2 (R1.2), U7.4 (E)
unnamed: RN5.3 (R2.1), U3.14 (O5)
unnamed: RN5.4 (R2.2), U7.2 (F)
unnamed: RN5.5 (R3.1), U3.13 (O6)
unnamed: RN5.6 (R3.2), U7.3 (G)
unnamed: RN5.7 (R4.1), U3.12 (O7)
unnamed: RN5.8 (R4.2), U7.7 (DP)
unnamed: RN6.1 (R1.1), U4.19 (O0)
unnamed: RN6.2 (R1.2), U8.10 (A)
unnamed: RN6.3 (R2.1), U4.18 (O1)
unnamed: RN6.4 (R2.2), U8.9 (B)
unnamed: RN6.5 (R3.1), U4.17 (O2)
unnamed: RN6.6 (R3.2), U8.8 (C)
unnamed: RN6.7 (R4.1), U4.16 (O3)
unnamed: RN6.8 (R4.2), U8.5 (D)
unnamed: RN7.1 (R1.1), U4.15 (O4)
unnamed: RN7.2 (R1.2), U8.4 (E)
unnamed: RN7.3 (R2.1), U4.14 (O5)
unnamed: RN7.4 (R2.2), U8.2 (F)
unnamed: RN7.5 (R3.1), U4.13 (O6)
unnamed: RN7.6 (R3.2), U8.3 (G)
unnamed: RN7.7 (R4.1), U4.12 (O7)
unnamed: RN7.8 (R4.2), U8.7 (DP)
unnamed: RN8.1 (R1.1), U5.19 (O0)
unnamed: RN8.2 (R1.2), U9.10 (A)
unnamed: RN8.3 (R2.1), U5.18 (O1)
unnamed: RN8.4 (R2.2), U9.9 (B)
unnamed: RN8.5 (R3.1), U5.17 (O2)
unnamed: RN8.6 (R3.2), U9.8 (C)
unnamed: RN8.7 (R4.1), U5.16 (O3)
unnamed: RN8.8 (R4.2), U9.5 (D)
unnamed: RN9.1 (R1.1), U5.15 (O4)
unnamed: RN9.2 (R1.2), U9.4 (E)
unnamed: RN9.3 (R2.1), U5.14 (O5)
unnamed: RN9.4 (R2.2), U9.2 (F)
unnamed: RN9.5 (R3.1), U5.13 (O6)
unnamed: RN9.6 (R3.2), U9.3 (G)
unnamed: RN9.7 (R4.1), U5.12 (O7)
unnamed: RN9.8 (R4.2), U9.7 (DP)
unnamed: C8.1, C9.1, C10.1, R2.1, R3.1, SW20.3 (A), U10.3 (E)

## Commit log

2025-09-25 breakout board
    [141_500SSPxS1M2xEA.stp, 7-SEG_DISP.kicad_sch, 8051.kicad_pcb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]
2025-09-26 silkscreen bs
    [8051_breakout.kicad_pcb]
2025-09-26 5v power plane
    [8051.kicad_pcb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]
2025-09-28 dev board gerbers
    [8051-B_Cu.gbr, 8051-B_Mask.gbr, 8051-B_Paste.gbr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]
2025-10-06 gerber fix
    [8051_breakout-B_Cu.gbr, 8051_breakout-B_Mask.gbr, 8051_breakout-B_Paste.gbr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]
2025-12-30 fixed footprint 8051
    [8051-B_Cu.gbr, 8051-B_Mask.gbr, 8051-B_Paste.gbr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]
